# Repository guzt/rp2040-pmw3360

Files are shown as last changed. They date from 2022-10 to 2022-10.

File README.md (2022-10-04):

A WIP split keyboard with a USB hub and two trackballs in the center:

1. an optical trackball for mouse control
1. a tiny blackberry trackball for scroll

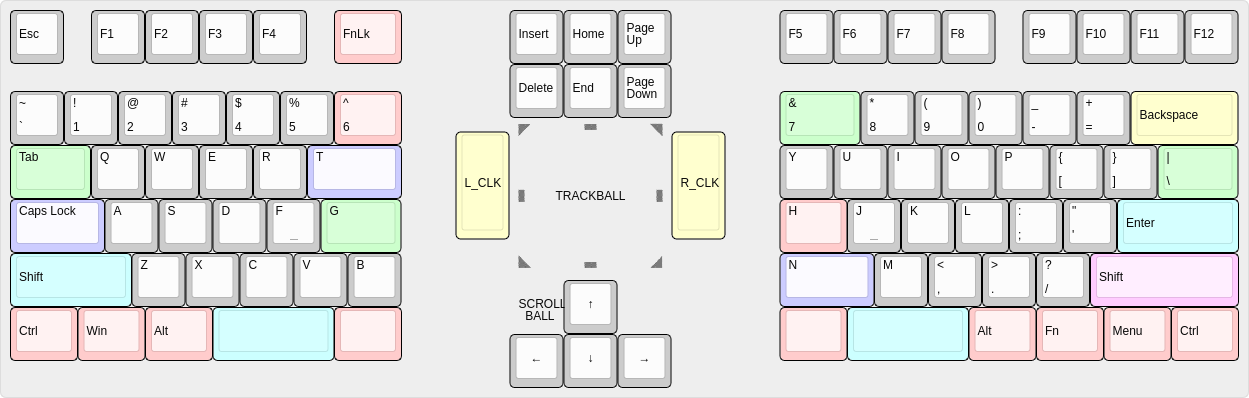
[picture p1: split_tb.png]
layout


Based on:

# RP2040+PMW3360

This repository contains design files and code for a PCB carrying Raspberry Pi's RP2040 chip and the PixArt PMW3360 optical mouse sensor. They can be used for rapid prototyping of USB mice and trackballs.

The files in the [fabrication](fabrication) folder can be used to order this board from JLCPCB with SMT assembly. The board you get includes everything except the sensor. If some of the specific components are out of stock, try to find an equivalent with the same package and parameters.

The sensor chip should be soldered on the bottom side (the opposite side from all the other components). The dot marks pin 1. The optic goes on the top side.

If you're looking for a convenient way of mounting mouse button switches in a case, perhaps [this repository](https://github.com/jfedor2/mouse-switch-mount-pcb) will be of use.

Examples of devices made using this board:

* [Trackball 7](https://www.prusaprinters.org/prints/83631-trackball-7)
* [Trackball 8](https://www.prusaprinters.org/prints/84148-trackball-8)
* [Spherical trackball](https://www.prusaprinters.org/prints/85053-spherical-trackball)
* [Two-ball trackball](https://github.com/jfedor2/two-ball-trackball)
* [Mouse 1](https://www.prusaprinters.org/prints/87379-mouse-1)
* [Mouse 2](https://www.prusaprinters.org/prints/88403-mouse-2)
* [Trackball with twist-to-scroll](https://github.com/jfedor2/twist-to-scroll-trackball)
* [Trackball with scroll ring](https://github.com/jfedor2/scroll-ring-trackball)
* [Mouse 4](https://www.prusaprinters.org/prints/127451-mouse-4)
* [Trackball 15](https://www.prusaprinters.org/prints/131450-trackball-15), [15b/c](https://www.printables.com/model/263616-trackball-15bc), [15d/e](https://www.printables.com/model/267954-trackball-15de)

PCB render

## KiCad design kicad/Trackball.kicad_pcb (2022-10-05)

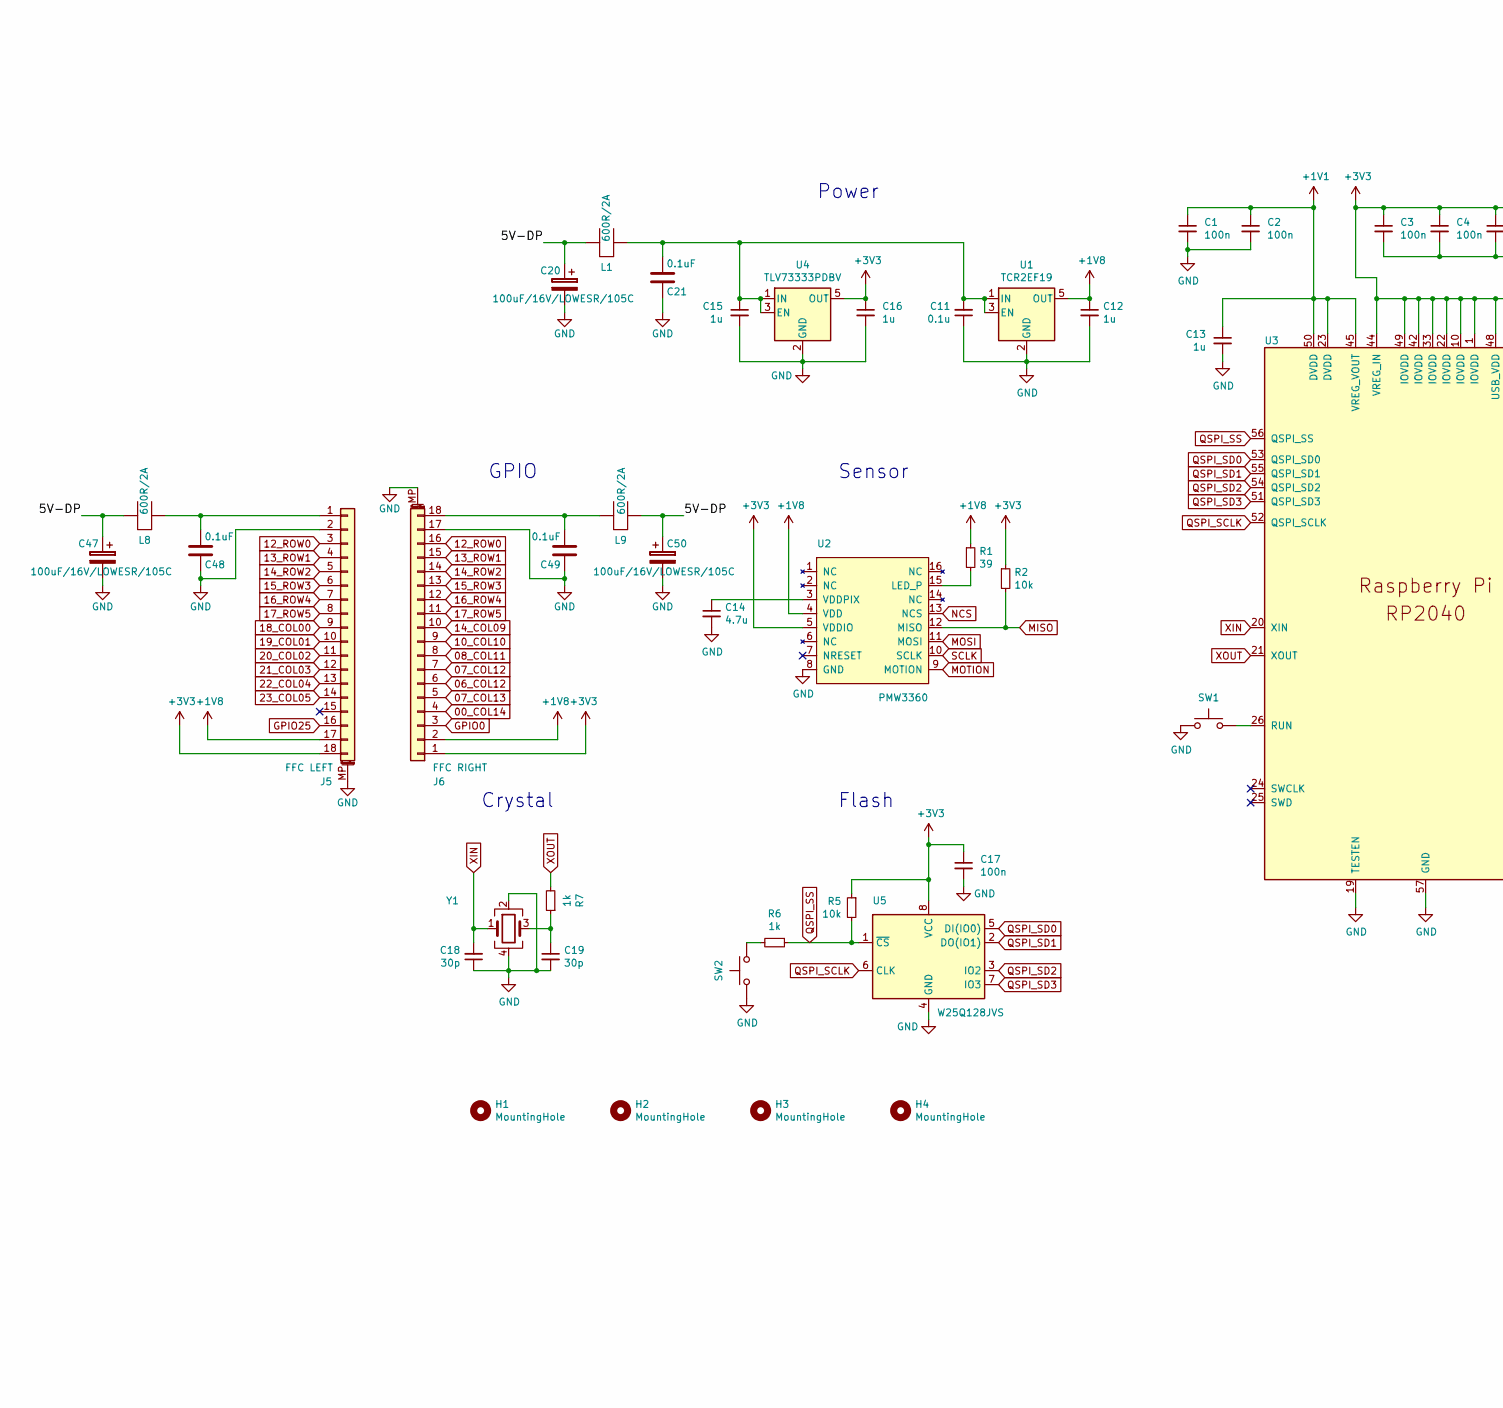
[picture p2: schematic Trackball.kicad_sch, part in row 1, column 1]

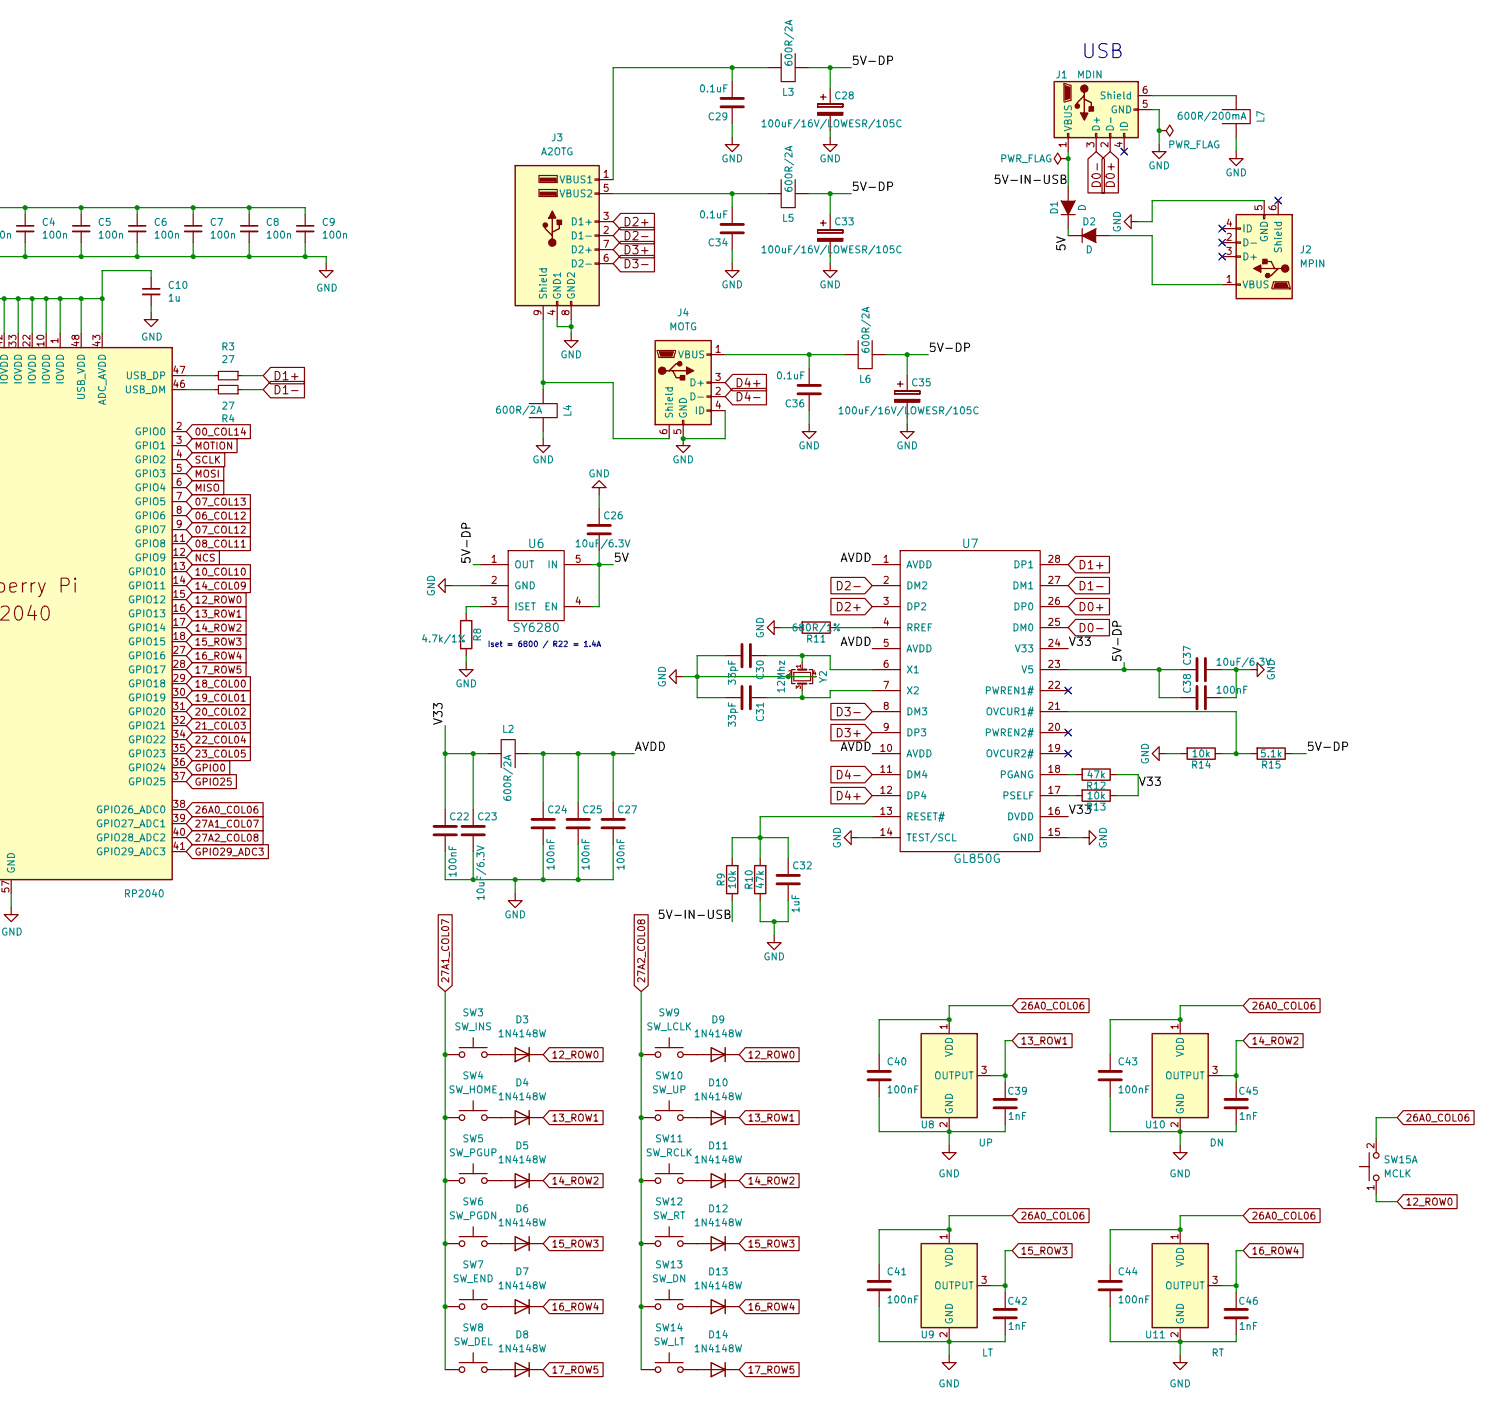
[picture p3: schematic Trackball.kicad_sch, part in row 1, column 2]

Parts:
C1, C2, C3, C4, C5, C6, C7, C8, C9, C17: 100n; C_0402_1005Metric; LCSC C1525
C10, C13, C15, C16: 1u; C_0402_1005Metric; LCSC C52923
C11: 0.1u; C_0402_1005Metric; LCSC C14663
C12: 1u; C_0402_1005Metric; LCSC C15849
C14: 4.7u; C_0402_1005Metric; LCSC C23733
C18, C19: 30p; C_0402_1005Metric; LCSC C1570
C20, C28, C33, C35, C47, C50: 100uF/16V/LOWESR/105C; CP_Elec_6.3x5.9
C21, C29, C34, C36, C48, C49: 0.1uF; C_0402_1005Metric
C22, C24, C25, C27, C38, C40, C41, C43, C44: 100nF; C_0402_1005Metric
C23, C26, C37: 10uF/6.3V; C_0402_1005Metric
C30, C31: 33pF; C_0402_1005Metric
C32: 1uF; C_0402_1005Metric
C39, C42, C45, C46: 1nF; C_0402_1005Metric
D1, D2: D; D_SOD-323
D3, D4, D5, D6, D7, D8, D9, D10, D11, D12, D13, D14: 1N4148W; D_SOD-323
H1, H2, H3, H4: MountingHole; MountingHole_3.2mm_M3
J1: MDIN; USB_Micro-B_Molex-105017-0001
J2: MPIN; USB_Micro-B_Molex-105017-0001
J3: A2OTG; USB_A_Wuerth_61400826021_Horizontal_Stacked
J4: MOTG; USB_Micro-B_Molex-105017-0001
J5: FFC LEFT; TE_1-1734839-8_1x18-1MP_P0.5mm_Horizontal
J6: FFC RIGHT; TE_1-1734839-8_1x18-1MP_P0.5mm_Horizontal
L1, L2, L3, L4, L5, L6, L8, L9: 600R/2A; R_0805_2012Metric
L7: 600R/200mA; R_0805_2012Metric
R1: 39; R_0402_1005Metric; LCSC C25110
R2, R5: 10k; R_0402_1005Metric; LCSC C25744
R3, R4: 27; R_0402_1005Metric; LCSC C138021
R6, R7: 1k; R_0402_1005Metric; LCSC C11702
R8: 4.7k/1%; R_0402_1005Metric
R9, R13, R14: 10k; R_0402_1005Metric
R10, R12: 47k; R_0402_1005Metric
R11: 680R/1%; R_0402_1005Metric
R15: 5.1k; R_0402_1005Metric
SW1: RUN; SW_SPST_Omron_B3FS-100xP; LCSC C271750
SW2: FLASH; SW_SPST_Omron_B3FS-100xP; LCSC C271750
SW3: SW_INS; SW_Cherry_MX_1.00u_PCB
SW4: SW_HOME; SW_Cherry_MX_1.00u_PCB
SW5: SW_PGUP; SW_Cherry_MX_1.00u_PCB
SW6: SW_PGDN; SW_Cherry_MX_1.00u_PCB
SW7: SW_END; SW_Cherry_MX_1.00u_PCB
SW8: SW_DEL; SW_Cherry_MX_1.00u_PCB
SW9: SW_LCLK; SW_Cherry_MX_2.00u_Vertical_PCB
SW10: SW_UP; SW_Cherry_MX_1.00u_PCB
SW11: SW_RCLK; SW_Cherry_MX_2.00u_Vertical_PCB
SW12: SW_RT; SW_Cherry_MX_1.00u_PCB
SW13: SW_DN; SW_Cherry_MX_1.00u_PCB
SW14: SW_LT; SW_Cherry_MX_1.00u_PCB
SW15: MCLK; SW_SPST_TL3342
U1: TCR2EF19; SOT-23-5; LCSC C146366
U2: PMW3360
U3: RP2040; RP2040-QFN-56; LCSC C2040
U4: TLV73333PDBV; SOT-23-5; LCSC C134139
U5: W25Q128JVS; SOIC-8_5.23x5.23mm_P1.27mm; LCSC C97521
U6: SY6280; SOT-23-5
U7: GL850G; SSOP-28_5.3x10.2mm_P0.65mm
U8: UP; MT8691DT-1608
U9: LT; MT8691DT-1608
U10: DN; MT8691DT-1608
U11: RT; MT8691DT-1608
Y1: 12MHz; Crystal_SMD_3225-4Pin_3.2x2.5mm; LCSC C9002
Y2: 12Mhz; Crystal_SMD_3225-4Pin_3.2x2.5mm

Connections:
00_COL14: J6.4, U3.2 (GPIO0)
06_COL12: J6.6, U3.8 (GPIO6)
07_COL12: J6.7, U3.9 (GPIO7)
07_COL13: J6.5, U3.7 (GPIO5)
08_COL11: J6.8, U3.11 (GPIO8)
10_COL10: J6.9, U3.13 (GPIO10)
12_ROW0: D3.1 (K), D9.1 (K), J5.3, J6.16, SW15.1 (C), U3.15 (GPIO12)
13_ROW1: C39.1, D4.1 (K), D10.1 (K), J5.4, J6.15, U3.16 (GPIO13), U8.3 (OUTPUT)
14_COL09: J6.10, U3.14 (GPIO11)
14_ROW2: C45.1, D5.1 (K), D11.1 (K), J5.5, J6.14, U3.17 (GPIO14), U10.3 (OUTPUT)
15_ROW3: C42.1, D6.1 (K), D12.1 (K), J5.6, J6.13, U3.18 (GPIO15), U9.3 (OUTPUT)
16_ROW4: C46.1, D7.1 (K), D13.1 (K), J5.7, J6.12, U3.27 (GPIO16), U11.3 (OUTPUT)
17_ROW5: D8.1 (K), D14.1 (K), J5.8, J6.11, U3.28 (GPIO17)
18_COL00: J5.9, U3.29 (GPIO18)
19_COL01: J5.10, U3.30 (GPIO19)
20_COL02: J5.11, U3.31 (GPIO20)
21_COL03: J5.12, U3.32 (GPIO21)
22_COL04: J5.13, U3.34 (GPIO22)
23_COL05: J5.14, U3.35 (GPIO23)
26A0_COL06: C40.2, C41.2, C43.2, C44.2, SW15.2 (D), U3.38 (GPIO26_ADC0), U8.1 (VDD), U9.1 (VDD), U10.1 (VDD), U11.1 (VDD)
27A1_COL07: SW3.1, SW4.1, SW5.1, SW6.1, SW7.1, SW8.1, U3.39 (GPIO27_ADC1)
27A2_COL08: SW9.1, SW10.1, SW11.1, SW12.1, SW13.1, SW14.1, U3.40 (GPIO28_ADC2)
+1V1: C1.1, C2.1, C13.1, U3.23 (DVDD), U3.45 (VREG_VOUT), U3.50 (DVDD)
+1V8: C12.1, J5.17, J6.2, R1.1, U1.5 (OUT), U2.4 (VDD)
+3V3: C3.1, C4.1, C5.1, C6.1, C7.1, C8.1, C9.1, C10.1, C16.1, C17.1, J5.18, J6.1, R2.1, R5.1, U2.5 (VDDIO), U3.1 (IOVDD), U3.10 (IOVDD), U3.22 (IOVDD), U3.33 (IOVDD), U3.42 (IOVDD), U3.43 (ADC_AVDD), U3.44 (VREG_IN), U3.48 (USB_VDD), U3.49 (IOVDD), U4.5 (OUT), U5.8 (VCC)
/5V: C26.2, D1.1 (K), D2.1 (K), U6.4 (EN), U6.5 (IN)
/5V-DP: C20.1, C28.1, C33.1, C35.1, C37.1, C38.1, C47.1, C50.1, L1.1, L3.1, L5.1, L6.1, L8.1, L9.1, R15.1, U6.1 (OUT), U7.23 (V5)
/5V-IN-USB: D1.2 (A), J1.1 (VBUS), R9.1
/AVDD: C24.1, C25.1, C27.1, L2.2, U7.1 (AVDD), U7.5 (AVDD), U7.10 (AVDD)
/V33: C22.1, C23.1, L2.1, R12.1, R13.1, U7.16 (DVDD), U7.24 (V33)
D0+: J1.2 (D-), U7.26 (DP0)
D0-: J1.3 (D+), U7.25 (DM0)
D1+: R3.1, U7.28 (DP1)
D1-: R4.1, U7.27 (DM1)
D2+: J3.3 (D1+), U7.3 (DP2)
D2-: J3.2 (D1-), U7.2 (DM2)
D3+: J3.7 (D2+), U7.9 (DP3)
D3-: J3.6 (D2-), U7.8 (DM3)
D4+: J4.3 (D+), U7.12 (DP4)
D4-: J4.2 (D-), U7.11 (DM4)
GND: C1.2, C2.2, C3.2, C4.2, C5.2, C6.2, C7.2, C8.2, C9.2, C10.2, C11.1, C12.2, C13.2, C14.2, C15.2, C16.2, C17.2, C18.1, C19.2, C20.2, C21.1, C22.2, C23.2, C24.2, C25.2, C26.1, C27.2, C28.2, C29.1, C30.2, C31.2, C32.2, C33.2, C34.1, C35.2, C36.1, C37.2, C38.2, C39.2, C40.1, C41.1, C42.2, C43.1, C44.1, C45.2, C46.2, C47.2, C48.1, C49.1, C50.2, J1.5 (GND), J2.5 (GND), J3.4 (GND1), J3.8 (GND2), J4.4 (ID), J4.5 (GND), J5.2, J5.MP (MountPin), J6.17, J6.MP (MountPin), L4.2, L7.2, R8.2, R10.1, R11.2, R14.2, SW1.1, SW2.1, U1.2 (GND), U2.8 (GND), U3.19 (TESTEN), U3.57 (GND), U4.2 (GND), U5.4 (GND), U6.2 (GND), U7.14 (TEST/SCL), U7.15 (GND), U8.2 (GND), U9.2 (GND), U10.2 (GND), U11.2 (GND), Y1.2, Y1.4, Y2.2, Y2.4
GPIO0: J6.3, U3.36 (GPIO24)
GPIO25: J5.16, U3.37 (GPIO25)
GPIO29_ADC3: U3.41 (GPIO29_ADC3)
MISO: R2.2, U2.12 (MISO), U3.6 (GPIO4)
MOSI: U2.11 (MOSI), U3.5 (GPIO3)
MOTION: U2.9 (MOTION), U3.3 (GPIO1)
NCS: U2.13 (NCS), U3.12 (GPIO9)
unnamed: C11.2, C15.1, C21.2, L1.2, U1.1 (IN), U1.3 (EN), U4.1 (IN), U4.3 (EN)
unnamed: C14.1, U2.3 (VDDPIX)
unnamed: C19.1, R7.1, Y1.3
unnamed: C29.2, J3.1 (VBUS1), L3.2
unnamed: C30.1, U7.6 (X1), Y2.1
unnamed: C31.1, U7.7 (X2), Y2.3
unnamed: C32.1, R9.2, R10.2, U7.13 (RESET#)
unnamed: C34.2, J3.5 (VBUS2), L5.2
unnamed: C36.2, J4.1 (VBUS), L6.2
unnamed: C48.2, J5.1, L8.2
unnamed: C49.2, J6.18, L9.2
unnamed: D2.2 (A), J2.1 (VBUS)
unnamed: D3.2 (A), SW3.2
unnamed: D4.2 (A), SW4.2
unnamed: D5.2 (A), SW5.2
unnamed: D6.2 (A), SW6.2
unnamed: D7.2 (A), SW7.2
unnamed: D8.2 (A), SW8.2
unnamed: D9.2 (A), SW9.2
unnamed: D10.2 (A), SW10.2
unnamed: D11.2 (A), SW11.2
unnamed: D12.2 (A), SW12.2
unnamed: D13.2 (A), SW13.2
unnamed: D14.2 (A), SW14.2
unnamed: J1.6 (Shield), L7.1
unnamed: J3.9 (Shield), J4.6 (Shield), L4.1
unnamed: R1.2, U2.15 (LED_P)
unnamed: R3.2, U3.47 (USB_DP)
unnamed: R4.2, U3.46 (USB_DM)
unnamed: R6.2, SW2.2
unnamed: R8.1, U6.3 (ISET)
unnamed: R11.1, U7.4 (RREF)
unnamed: R12.2, U7.18 (PGANG)
unnamed: R13.2, U7.17 (PSELF)
unnamed: R14.1, R15.2, U7.21 (OVCUR1#)
unnamed: SW1.2, U3.26 (RUN)
QSPI_SCLK: U3.52 (QSPI_SCLK), U5.6 (CLK)
QSPI_SD0: U3.53 (QSPI_SD0), U5.5 (DI(IO0))
QSPI_SD1: U3.55 (QSPI_SD1), U5.2 (DO(IO1))
QSPI_SD2: U3.54 (QSPI_SD2), U5.3 (IO2)
QSPI_SD3: U3.51 (QSPI_SD3), U5.7 (IO3)
QSPI_SS: R5.2, R6.1, U3.56 (QSPI_SS), U5.1 (~CS)
SCLK: U2.10 (SCLK), U3.4 (GPIO2)
XIN: C18.2, U3.20 (XIN), Y1.1
XOUT: R7.2, U3.21 (XOUT)

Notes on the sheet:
GPIO
Crystal
Sensor
Power
Iset = 6800 / R22 = 1.4A
USB
Flash

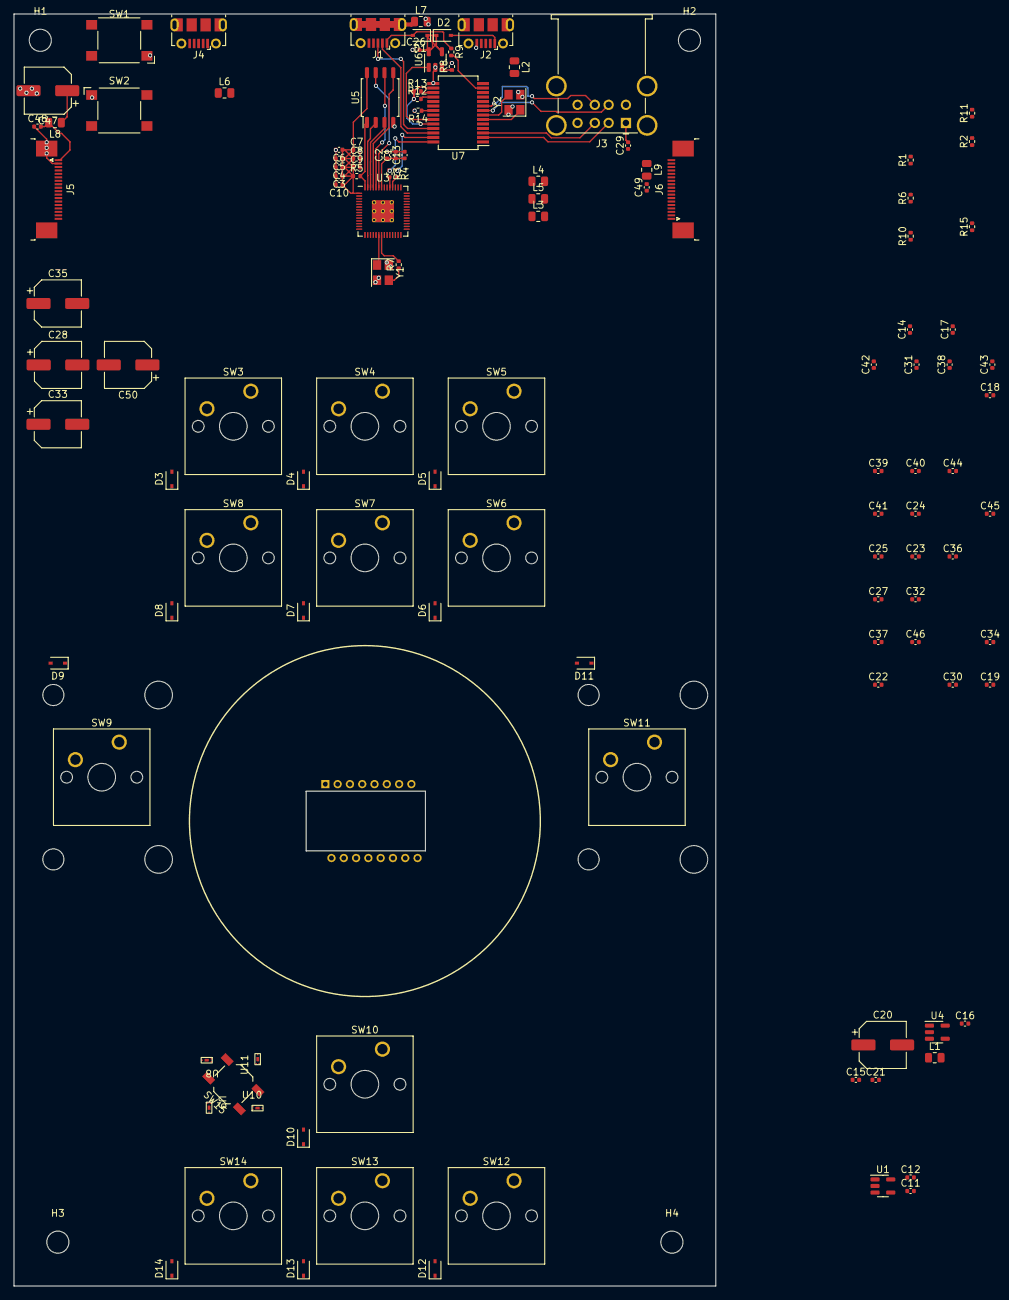
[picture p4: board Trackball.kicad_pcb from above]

Board: 2 copper layers, 101.6 x 184.2 mm, 126 parts (1 on the bottom side), 92 nets.
